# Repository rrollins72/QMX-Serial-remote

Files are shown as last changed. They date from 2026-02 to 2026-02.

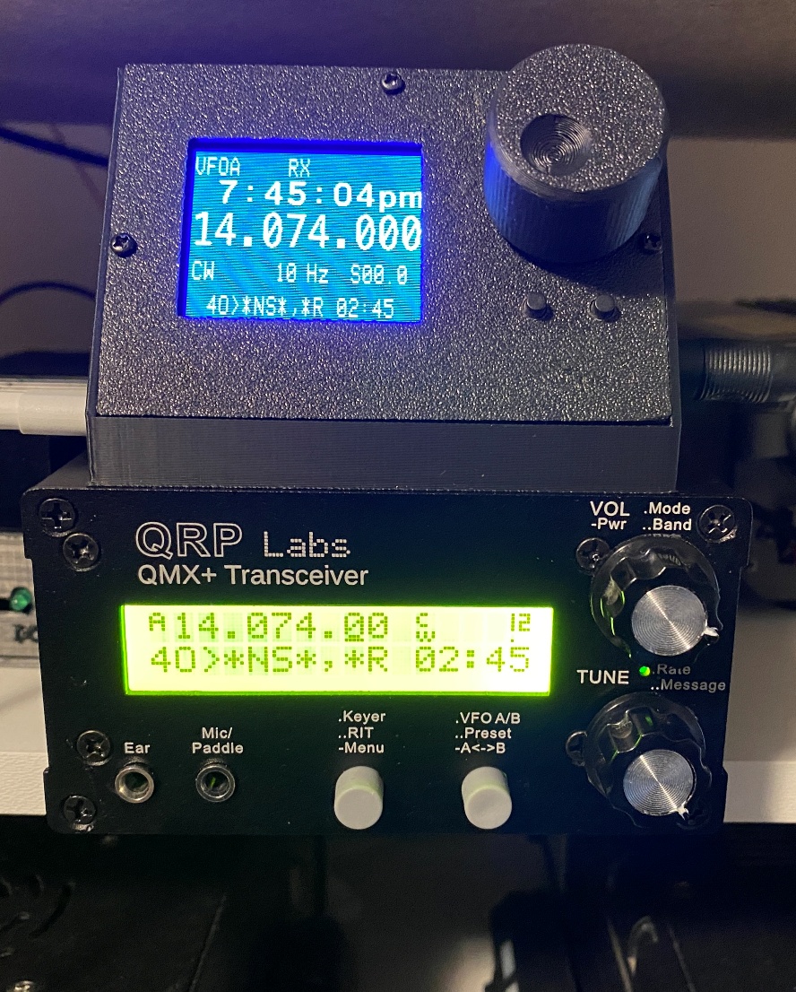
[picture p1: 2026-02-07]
enclosure/operating on qmx+.jpg

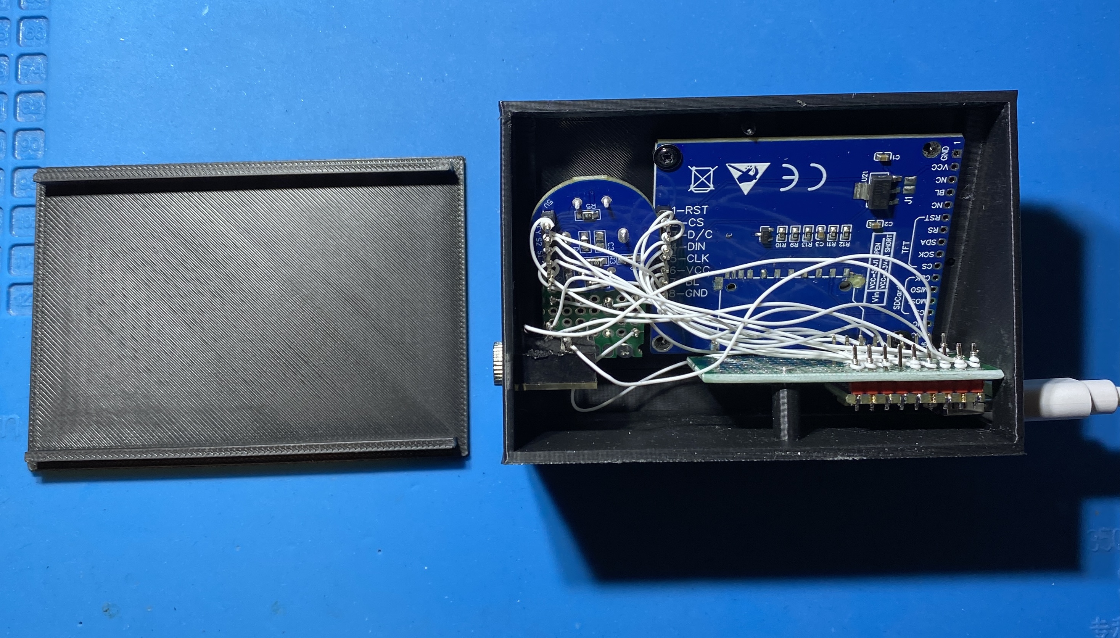
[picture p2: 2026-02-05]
enclosure/internals and wiring.jpg

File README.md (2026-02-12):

# QMX Remote using ESP32

**Fun little project**

A little background…I began experimenting with using a couple inexpensive ESP32
modules when they appeared on Aliexpress for less than \$5. I decided to get an
ESP32-C3 and an ESP32-S3 based small (zero sized) modules. I also had a few
ST7735 based displays that were needing to be utilized, so I decided to build a small
clock that would become an IoT device. That gave me some experience with the
Arduino IDE for ESP32 and graphics on the small display. I thought it would be
fun to figure out if I could talk to my QMX+ using the AUX serial port and the
ESP32 serial port.

Hats off to Hans Summers for a great design on the QMX/QMX+ and his stellar
documentation for the CAT command structures and the tools to monitor the CAT
commands to the unit. That made this effort much easier.

The ESP32-S3 I used is the (equivalent of a) Waveshare ESP32-S3-Zero, (see
https://www.waveshare.com/wiki/ESP32-S3-Zero) and it has a
limited number of IO pins due to the small package size. I decided to use 2
external switches and the rotary encoder switch for function selects, and a 1.8”
120x160 ST7735 display. The basic schematic is as shown:


Note that the display unit I chose had a 3.3V regulator on the board, so it needed 5V to run it. Others that don't have the regulator would run on 3.3V. The 3.3V output from the ESP32-S3-Zero is capable of about 30mA, so it should work OK.

The backlight is always enabled in this scheme. IO3 and IO7 could be used to
turn on and off the backlight, or to add another switch.

I did not put a battery in this set up, so it is powered from the USB-C cable
that is plugged into the ESP32-S3 board. (It draws about 30mA with the display
at full brightness).

I built the first pass on a breadboard and then put it all in a small 3D printed
enclosure with point-to-point wiring. I didn’t attempt to do a PCB for this
project.

Here is a photo of the finished device connected to the QMX+ showing the unit
connected to the QMX+ and operating.



# Operation summary

The remote display will connect to the QMX+ via the AUX serial port.

The serial interface baud rate is set to 19200, with 8N1. This will need to be set up on
the QMX+ using a USB serial port to control the menu system. Go to Main
menu\>Configuration\>System config\>GPS & Ser. Ports: Serial 1 on AUX: ENABLED,
Serial 1 baud: 19200. (Note: I tried using higher baud settings, but that
resulted in a lot of missed data, so settled on 19200).

There are 3 controls on the display:

The rotary knob with button on press, button A (left) and button B (right).

 # Functions

**Rotary knob** will normally adjust the frequency depending on the selected step
size. The step size is changed by a short press on the rotary knob. The step
sizes are 10Hz, 100Hz, 1kHz, 10kHz.

**The band** can also be changed by a double click on the rotary knob (it must be
\~400ms between presses). The band will be shown in the lowest display area. The rotary
knob can be turned to select the band desired, then the knob pressed to verify
and the band will be changed to the selected. (This process needs some
refinement since it required a change to the VFOA frequency to make the change,
so previous VFOA settings are lost).

**The volume** can also be changed by a long press on the rotary knob. The volume
(Audio Gain) is set as desired. This is the raw level and is capable of any value
between 1 and 799. You can set the internal QMX+ volume step, which defaults to
1dB, this is 4 raw steps. I left this at the raw step (.25dB). The Vol is displayed
in the lowest display area, similar to the band selection.

**Button A** is on the left and below the rotary control. It simply controls the
selected VFOA or B.

**Button B** is on the right and below the rotary control. It controls the selected
mode. The modes are cycled through: CW, DIGI, USB, LSB (same as QMX).

Display updates occur on a 1 second increment so there can be some visible lag
on some data presented on the display. The updates from the rotary encoder are
done during the main loop and are near real time.

# Software and IDE build

The Arduino IDE 2.3.7 on Win11 was used to build the code for this project. It will
require the board manager 'esp-32 by Espressif Systems' be installed, the 'OneButton' library and the
'ST7735_LTSM' library to be installed. Because of the limited pins on the
ESP32-S3-Zero package, **a modification to the file noted in the code snippet below needs to be made to
provide an SPI interface on the IO pins used**. This is to change from the
defaults. **Here is the note in the code**:

// NOTE: To map the SPI to available pins, a change to the file in this location is necessary:\
// C:\\Users\\xxxxx\\AppData\\Local\\Arduino15\\packages\\esp32\\hardware\\esp32\\3.x.x\\variants\\waveshare_esp32_s3_zero\\pins_arduino.h\
// Mapping based on the ESP32S3 data sheet - alternate for SPI2\
// static const uint8_t SS = 10; // FSPICS0\
// static const uint8_t MOSI = 11; // FSPID\
// static const uint8_t MISO = 13; // FSPIQ\
// static const uint8_t SCK = 12; // FSPICLK

(in the pins_arduino.h file, change to the pins shown: 10, 11, 13, and 12 and save the file).
This gives the display a fast update capability and works well.

The chosen frequencies for the band-switch are as follows:\
160M 1.9MHz\
80M 3.6MHz\
60M 5.3585MHz\
40M 7.1MHz\
30M 10.125MHz\
20M 14.0475MHz\
17M 18.110MHz\
15M 21.2MHz\
12M 24.930MHz\
10M 28.3MHz\
6M 50.1MHz

These can be changed in the code if needed. As built, they are constants.

I elected to have the display show my local time instead of UTC, though the UTC
is displayed as shown on the QMX+ LCD bottom line. This is easily changed
in the code if desired.

# Enclosure

The STL files for the enclosure are included in the project files. These were
done in Tinker CAD. 

# Caveats and Thoughts

The code for this was built without the use of any extensive buffer management,
and with easily accessible libraries within the Arduino IDE. That said, there is
a slight lag time during the 1 second display refresh on reading the rotary
encoder, so it may feel like it misses once in a while.

Band switching using the double-click on the encoder is not fully consistent,
but it is quite functional. Just takes some getting used to. A third control switch
could be added to make this easier, but I had already built the enclosure by the
time I decided to add band switching.

I also built a version of the code for a larger 2.4" TFT display using the 
ST7789 driver. This is a 320x240 display, so it takes a lot longer to refresh
the screen and it isn't as responsive to the rotary control. It still works well
enough and is bigger to look at. I did not put that version in an enclosure. The code is 
included in this project area.

I did test this with a 15 foot audio cable and didn't see any issues with the 
serial data stream between the remote and the QMX+ (at 19200 baud). It appears
to be quite robust.

The ESP32-S3 has built in WiFi or Bluetooth, so it would be possible to create a server page
that could also show the same information as the display, but that is beyond
what I intended for this effort. It would also draw a lot more power since the
WiFi would need to be active to make it functional. Since ESP32-S3 does not support a Bluetooth SPP
stack it can’t be fully wireless to the QMX+ with simple Bluetooth serial
modules either, so that was not considered.

I don't have a QMX, but the QMX does have the AUX port (internally) so it could be utilized but would require
adding wires and bringing them out to a connector. 

# Improvements?

Adding a small battery to allow the unit to run without power from USB will be
a future update. I will use USB for charging.

# Possible Issues

With the remote running, I have noticed that if I am also running WSJT-X for a while that the QMX+ frequency
for the selected VFO gets set to 0. It is a bit random but quite repeatable. I
have not discovered the cause. A band change either on the remote or in WSJT-X
will set the frequency again. WSJT-X does not show that the frequency has changed,
but the QMX+ and the remote show the frequency of 0. This also happened with JS8Call.
JS8Call did show the frequency change.

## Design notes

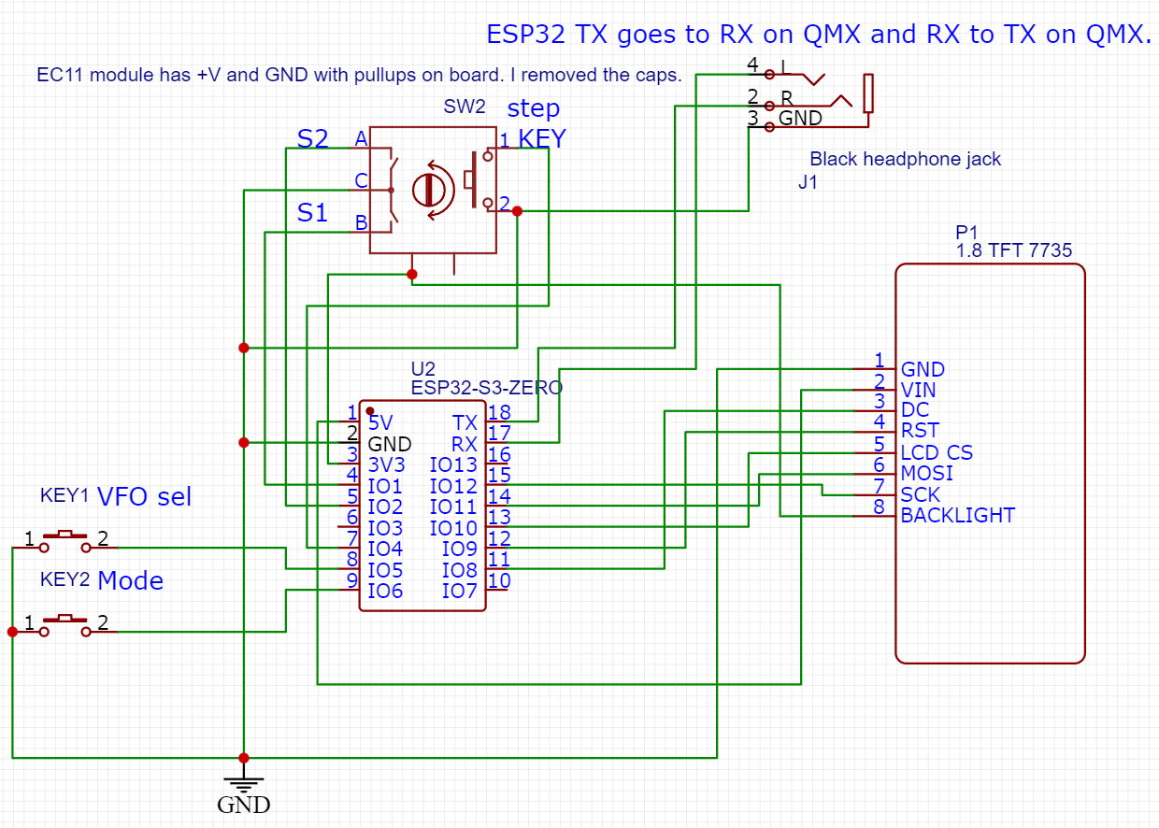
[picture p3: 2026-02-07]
enclosure/schematic.png

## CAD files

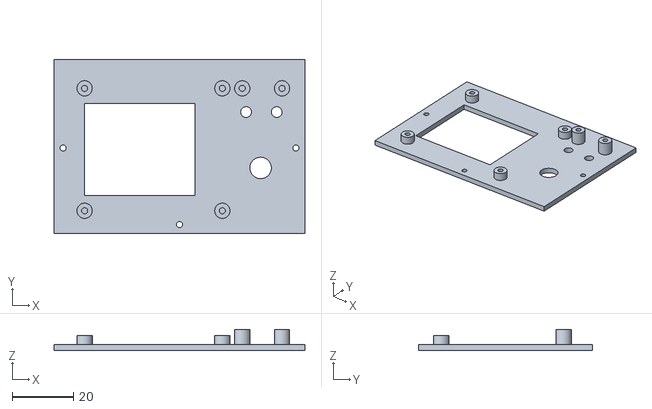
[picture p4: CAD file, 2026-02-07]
enclosure/qmxremote_face.stl
82.0 x 57.0 x 7.00

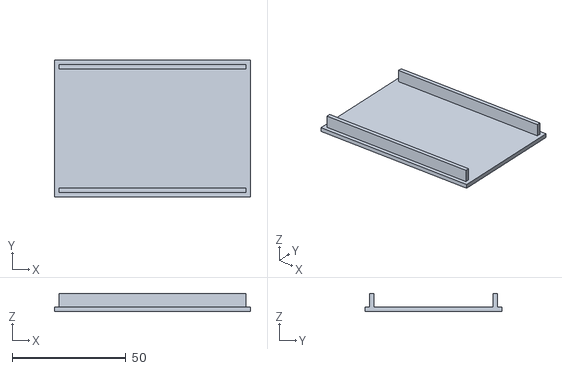
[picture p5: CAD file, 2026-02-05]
enclosure/qmxremote_box-back.stl
86.0 x 60.0 x 8.00

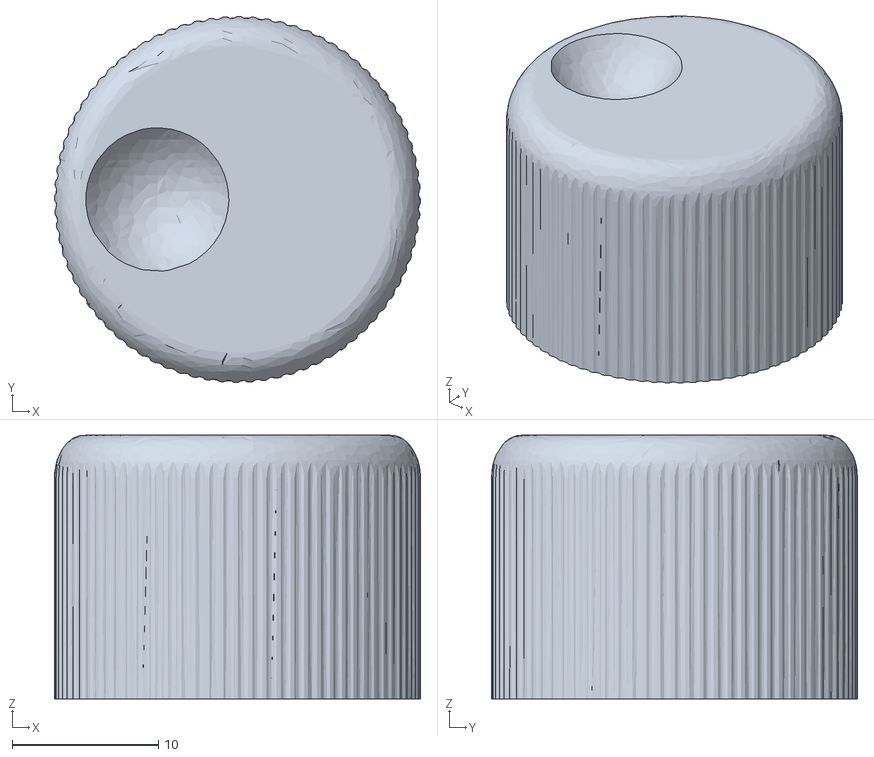
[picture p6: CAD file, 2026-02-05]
enclosure/25mm-knob1.stl
25.0 x 25.0 x 18.0

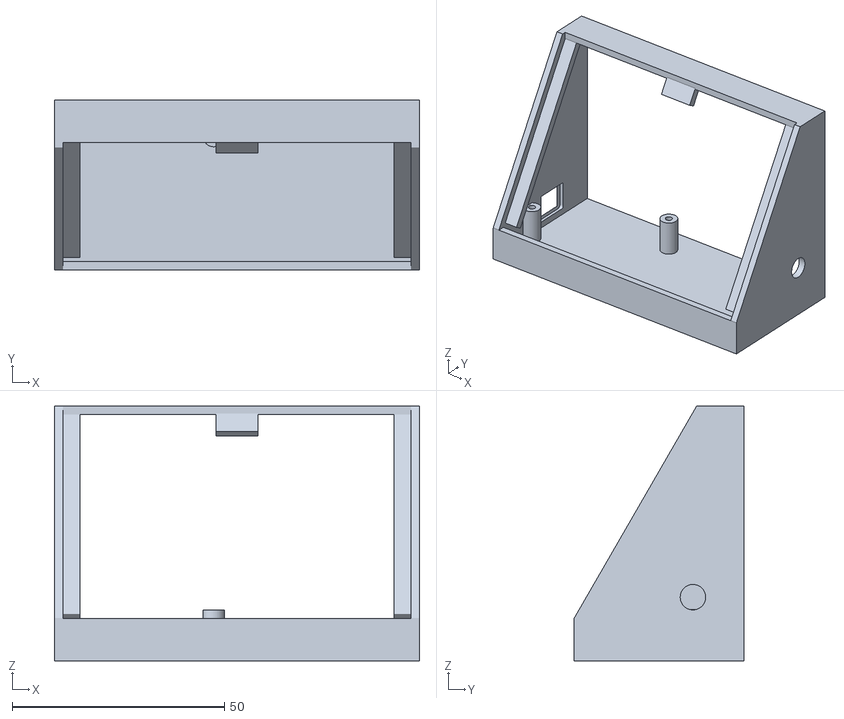
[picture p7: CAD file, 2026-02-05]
enclosure/qmxremote-box.stl
86.0 x 40.0 x 60.0

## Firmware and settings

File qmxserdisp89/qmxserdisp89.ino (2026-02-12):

///////////////////////////////////////////////////////////////////////
//	QMX Remote display
// This sketch using an ESP32-S3 processor and ST7735 display receiving
// serial data on TX/RX UART2 and using a rotary encoder to change frequency
// of the QRP Labs QMX+ tranceiver. It was done as an experiment to see how
// well the ESP32-S3 could handle the load, and it proved that is it quite
// capable.
// A ESP32-S3 Zero platform was used. Readily available for about $5 from Aliexpres
// The display is a 1.8" 160x120 TFT LCD with a ST7735 driver. 
// The Arduino IDE was used for this development. 
//	The esp32 board manager needs to be installed. The Waveshare ESP32-S3-Zero board is selected.
//	The driver for the display is the ST7735_LTSM by Gavin Lyons. Fonts are from that installation.
//		This driver is much faster than the ucg driver, so is necessary for this implementation 
//
//Operation summary
//The remote display will connect to the QMX+ via the AUX serial port. The serial interface baud rate is set to 19200, with 8N1. 
//This will need to be set up on the QMX using a USB serial port to control the menu system.
//Go to Main menu>Configuration>System config>GPS & Ser. Ports: Serial 1 on AUX: ENABLED, Serial 1 baud: 19200.
//(Note: I tried using higher baud settings, but that resulted in a lot of missed data, so settled on 19200).
//
//There are 3 controls on the display:
//The rotary knob with button on press, button A (left) and button B (right).
//Functions:
//Rotary knob will normally adjust the frequency depending on the selected step size. 
//The step size is changed by a short press on the rotary knob. The step sizes are 10Hz, 100Hz, 1kHz, 10kHz. 
//The band can also be changed by a double click on the rotary knob (it must be ~400ms or less). 
//The band will be shown in the lowest display area. 
//The rotary knob can be turned to select the band desired, then the knob pressed to verify 
//and the band will be changed to the selected. 
//(This process needs some refinement since it required a change to the VFOA frequency to make the change, 
//so previous VFOA settings are lost).
//The rotary knob can also be used to adjust the volume with a long press (>600ms).
//The volume (Analog Gain) is shown in the lower LCD and can be adjusted to a desired listening level,
//then a short press on the knob will set it to that and return to frequency adjust.
//Button A is on the left and below the rotary control. It simply controls the selected VFOA or B. 
//Button B is on the right and below the rotary control. It controls the selected mode. 
//The modes are cycled through: CW, DIGI, USB, LSB (same as QMX).
//
//Display updates occur on a 1 second increment so there can be some visible lag on some data presented on the display. 
//The updates from the rotary encoder are done during the main loop and are near real time. 
//The current build is set up for displaying MST from the clock, but this can be turned off or adjusted
//
//  
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
//////////////////////////////////////////////////////////////////////////
//
// The signals on the ST7735 and hook up to the ESP32-S3 Zero are as follows:
// ST7735   S3
//  GND     GND (pin 2)
//  VDD     5V(pin 1) The display has a 3.3V regulator on it-needs 5v.
//  SCL     SCK (GP12)
//  SDA     MOSI (GP11)
//  RST     GP9 
//  DC(RS)  GP8      
//  CS(SS)  GP10 
//  BKLT    to 3.3V on pin 1
//
/////////************** NOTE *******************************************
//  NOTE: To map the SPI to available pins, a change to the file in this location is necessary: 
//  C:\Users\xxxxx\AppData\Local\Arduino15\packages\esp32\hardware\esp32\3.x.x\variants\waveshare_esp32_s3_zero\pins_arduino.h:
//   Mapping based on the ESP32S3 data sheet - alternate for SPI2
//    static const uint8_t SS = 10;    // FSPICS0
//    static const uint8_t MOSI = 11;  // FSPID
//    static const uint8_t MISO = 13;  // FSPIQ
//    static const uint8_t SCK = 12;   // FSPICLK
//
// IF THERE IS AN UPDATE TO THE ESP32 PACKAGE THEN THIS WILL CHANGE, so need to be aware of it
//
/////////////////////////////////////////////////////////////////////////
//
/////////****************************************************************
// The serial interface will be based on the OnReceive demo structure-it is clean works well
// See QMX CAT document for information
////////////////////////////////////////
//

// libraries for display
#include "ST7789_LTSM.hpp"
// Included Fonts 
#include <fonts_LTSM/FontArialRound_LTSM.hpp>
#include <fonts_LTSM/FontRetro_LTSM.hpp>
#include <fonts_LTSM/FontGroTesk_LTSM.hpp>
#include <fonts_LTSM/FontGroTeskBig_LTSM.hpp>
#include <fonts_LTSM/FontSevenSeg_LTSM.hpp>
#include <fonts_LTSM/FontMint_LTSM.hpp>

////Display initialize
ST7789_LTSM myTFT;
bool bhardwareSPI = true; // true for hardware spi, false for software

/////// EC-11 rotary and buttons use ezButton
#include <ezButton.h>  // the library to use for SW button and other buttons
#include <Arduino.h>  // included for general serial use

/////// Onebutton ////////////
#include <OneButton.h>

///// Defines for IO pins used
#define CLK_PIN 1  // ESP32 pin gp1
#define DT_PIN 2   // ESP32 pin gp2
#define SW_PIN 4   // ESP32 pin gp4
#define BUTTON1 5  // GP5   general purpose button inputs
#define BUTTON2 6  // GP6

#define DIRECTION_CW 0   // clockwise direction
#define DIRECTION_CCW 1  // counter-clockwise direction

#define BAUD      19200 // Should be a reasonable speed for comms?
#define RXPIN     44     // GPIO 44 => RX for Serial2
#define TXPIN     43     // GPIO 43 => TX for Serial2

//////////////////// general declarations for global use and constants ///////////////////
// Rotary control globals
volatile int counter = 0;
volatile int direction = DIRECTION_CW;
volatile unsigned long last_time;  // for debouncing
volatile int statecnt = 0;

// Thresholds for rotary button press detects(milliseconds)
const int ShortPressTop  = 250;
const int LongPressBase   = 800;
const int DoubleClickGap = 400;
// Variables to track timing
unsigned long pressedTime  = 0;
unsigned long releasedTime = 0;
bool isWaitingForDouble    = false;
bool longPressDetected     = false;
bool VolProc = false;
int bstate = 0;		//button state is 0 to idle, 1 for long, 2 for double

int prev_counter = 0;
// The ezButton library is helpful for button management
//ezButton button(SW_PIN);	// create ezButton objects that attach to pins;
ezButton button1(BUTTON1);	//button for vfo selection
ezButton button2(BUTTON2);	//button for mode selection

OneButton button(SW_PIN, true); //active low true

// for S3 zero with RGB LED the IO is 21
#define RGB_BUILTIN 21
#define DEBUG 0

// Timer controls
unsigned long prevmils = 0;
unsigned long prevmils1 = 0;

/*************************************/
volatile size_t received_bytes = 0;
unsigned int fifoFull = 38;   // max data to receive
char Rcvbuf1[40];	// buffer to receive data
bool Rcvbufavail = 0;
bool Serconnavail = 0;	//set when a serial connection is valid
char FreqA[12] = "00014047500";
char FreqB[12] = "00007050000";
char Frcv[2] = "0";
char Ftrx[2] = "0";
char freqbuf[15];
char freqbuf1[15];
char AudGn[6] = "0180";
char timedat[9] = "12:00:00";     //time data hh:mm:ss
char timedat1[3];     // for am or pm
char timehr[3];       //HR portion
int AudGnVol = 180;	//base audio volume
int timehrdat;
int timelocalhr;
int rxtxchk = 0;   //receive/transmit state rx=0, tx=1
// For displaying local time offset from UTC from TM command
const int timelocal = -7;     //GMT offset for local MST
const bool TwelveHour = 1;	// For displaying 12 or 24 hour format
char smeterdat[6] = "00.1";   //smeter data in db xx.x 
char swrdat[6] = "1.00";      //swr reading x.xx:1
char lcddat[20] = {};     //lcd data-second line starts at 15 (16 bytes in)
//char infodat[36] = {};	  //info response 
char modedat[4] = {};     //mode info 1=LSB, 2=USB, 3=CW, 6=DIGI (FSK), 7=CWR
unsigned int modex = 2;	  // mode number as above
unsigned int frecvfo = 0; //receive vfo =0 for A, 1 for B, 3 for split
unsigned int ftrxvfo = 0; //same as receive vfo
unsigned int vfoaorb = 0;	//0=VFOA 1=VFOB
long Vfreqa = 0;
long Vfreqb = 0;
long stepset = 10;	//Step size in Hz for rotary step

int bandsel = 5;	//11 bands. 0=160m..10=6m 5=20m
bool bandselproc = 0;	//if in band select process

// Display constants
const char modLSB[] = "LSB  ";
const char modUSB[] = "USB  ";
const char modCW[] = "CW   ";
const char modCWR[] = "CWR  ";
const char modDIG[] = "DIGI ";
const char modDIGR[] = "DIGIR";
const char vfoAstr[] = "VFOA";
const char vfoBstr[] = "VFOB";
const char vfoSplit[] = "SPLIT";
const char stepHZ[] = "Hz  ";
const char stepkHZ[]= "kHz";
const char txstr[] = "TX";
const char rxstr[] = "RX";

// band set strings
const char bandtxt[11][10] = {"160m band"," 80m band"," 60m band"," 40m band"," 30m band"," 20m band"," 17m band"," 15m band"," 12m band"," 10m band","  6m band"};
//const char band160set[] = "00001900000";	//160M	1.9MHz
//const char band80set[] = "00003600000";		//80M	3.6MHz
//const char band60set[] = "00005358500";		//60M	5.3585MHz
//const char band40set[] = "00007100000";		//40M	7.1MHz
//const char band30set[] = "00010125000";		//30M	10.125MHz
//const char band20set[] = "00014150000";		//20M	14.150MHz
//const char band17set[] = "00018110000";		//17M	18.110MHz
//const char band15set[] = "00021200000";		//15M	21.2MHz
//const char band12set[] = "00024930000";		//12M	24.930MHz
//const char band10set[] = "00028300000";		//10M	28.3MHz
//const char band6set[] = "00050100000";		//6M	50.1MHz
const char bandsets[11][12] = {"00001900000","00003600000","00005358500","00007100000","00010125000","00014047500","00018110000","00021200000","00024930000","00028300000","00050100000" };

// Command constants
const char LCcmd[] = "LC;";   //LCD command-receive 35 chars
const char FAcmd[] = "FA;";   //Freq VFOA command-receive 14 chars, send 14 chars
const char FBcmd[] = "FB;";   //Freq VFOB command-receive 14 chars, send 14 chars
const char FRcmd[] = "FR;";   //Receive VFO command-receive 3 chars, send 3 chars
const char FTcmd[] = "FT;";   //Transmit VFO command-receive 3 chars, send 3 chars
const char MDcmd[] = "MD;";   //Mode command-receive 4 chars or send 4 chars
const char SMcmd[] = "SM;";   //Smeter command-receive 6 chars
const char TMcmd[] = "TM;";   //Time command-receive 9 chars
const char TQcmd[] = "TQ;";   //Tx/Rx command-receive 3 chars
const char SWcmd[] = "SW;";   //SWR during transmit-receive 6 chars
const char AGcmd[] = "AG;";   //Audio Gain command-receive 6 chars

///////////////////////////////////////////////////////////////
// This is called from the main loop to detect rotation changes
// There is sufficient main loop timing to make this work
///////////////////////////////////////////////////////////////
void rotloop () {
    if (statecnt == 0){
      if ((digitalRead(CLK_PIN) == LOW)&&(digitalRead(DT_PIN) == LOW)){
        statecnt = 1;
      }
    }
    if (statecnt == 1){
      if (digitalRead(CLK_PIN) == HIGH){
        statecnt = 2;
        last_time = millis();
      }
    }
    if (statecnt == 2){
      if ((millis() - last_time) > 2){
          if ((digitalRead(CLK_PIN) == HIGH)&&(digitalRead(DT_PIN) == HIGH)){
          // the encoder is rotating in counter-clockwise direction => decrease the counter
          counter--;
          direction = DIRECTION_CCW;
          statecnt = 0;
          }
          if ((digitalRead(CLK_PIN) == HIGH)&&(digitalRead(DT_PIN) == LOW)) {
          // the encoder is rotating in counter-clockwise direction => decrease the counter
          counter++;
          direction = DIRECTION_CW;
          statecnt = 0;
          }         
      }
    }
}

void RotButtonCheck(){
	button.tick(); // Monitor button state
  if (bstate == 1){	//long press
	  VolProc = true;
	    Serial2.write(AGcmd);	//request current audio gain on long press
		delay(5);  
  }
  else if (bstate == 2){ //double press
	    bandselproc = 1;  //enter band select
  }
}

// SHORT PRESS: Acts as the stop or regular press
void handleClick() {
  if (bstate != 0) {
    bstate = 0;
	if (bandselproc) {
		BandChgSnd();	//if in bandsel state, clear it and send command
		bandselproc = 0;
	}
	VolProc = 0;
  } 
  else {
    Serial.println("Short Press: Standard Action.");
	  if (stepset == 10) stepset = 100;
    else if (stepset == 100) stepset = 1000;
    else if (stepset == 1000) stepset = 10000;
    else if (stepset == 10000) stepset = 10;
    Botline();  // update display
  }
}
// DOUBLE PRESS: Starts the double routine
void handleDoubleClick() {
  if (bstate == 0) {
    bstate = 2;
  }
}

// LONG PRESS: Starts the long routine
void handleLongPressStart() {
  if (bstate == 0) {
    bstate = 1;
  }
}

////////////// Top line of the display ///////////////////
///////// Print time if receiving data from QMX, otherwise just show no connection /////
void Topline (){
  if (Serconnavail) {
    myTFT.setFont(FontGroTesk);
    myTFT.setTextColor(myTFT.C_WHITE, myTFT.C_BLUE);
    myTFT.setCursor(0,5);
    if (vfoaorb == 0) myTFT.print(vfoAstr);	//which vfo to show
    if (vfoaorb == 1) myTFT.print(vfoBstr);
    myTFT.setCursor(120,5);
    if (rxtxchk == 0) {
      myTFT.print(rxstr);
      myTFT.setCursor(160,5);
      myTFT.print("         ");
    }    
    else if (rxtxchk == 1) {
      myTFT.print(txstr);
      myTFT.setCursor(160,5);
      myTFT.print(" SWR ");
      myTFT.print(swrdat);
    } 						
    myTFT.setFont(FontMint);
    if (!TwelveHour) {
      myTFT.setCursor(35,35);
      myTFT.print (timedat);
    }
    else {
  // This converts the hour to local time for display
        timehrdat = atoi(timehr);     //to convert to local time for display
        timelocalhr = timehrdat+timelocal;  // Local offset from UTC
        if (timelocalhr < 0) timelocalhr = timelocalhr+24;
        if (TwelveHour) {
          if (timelocalhr >= 12) {
            if (timelocalhr > 12) timelocalhr = timelocalhr-12;
          timedat1[0] = 'p';
          }
          else {
            if (timelocalhr == 0) timelocalhr = 12;	
            timedat1[0] = 'a';
          }
          timedat1[1] = 'm';
          timedat1[2] = 0;
        }
        itoa (timelocalhr,timehr,10);
        if (timelocalhr < 10) {   // can pad with a 0 or space if leading 0 not desired
          if (TwelveHour) timedat[0] = ' ';
          else timedat[0] = '0';
          timedat[1] = timehr[0];
        }
        else {
          timedat[0] = timehr[0];
          timedat[1] = timehr[1];
        }
      myTFT.setCursor(50,40);
      myTFT.print (timedat);
      myTFT.print ("  ");
      myTFT.setFont(FontGroTesk);
      myTFT.setCursor(250,40);
      myTFT.print (timedat1);
    }
  }
  else {
    myTFT.setFont(FontGroTesk);
    myTFT.setCursor(50,40);
    myTFT.print ("*******        ");
    myTFT.setCursor(50,40);
    myTFT.print ("no coms ");
  }
}

//////////// lower display area, for mode and step and Smeter //////////
void Botline (){
	myTFT.setFont(FontGroTesk);
	myTFT.setCursor(2,165);
  switch (modex){
      case 1:
          myTFT.print (modLSB);
          break;
      case 2:
          myTFT.print (modUSB);
          break;
      case 3:
          myTFT.print (modCW);
          break;
      case 6:
          myTFT.print (modDIG);
          break;
      case 7:
          myTFT.print (modCWR);
          break;
      case 9:
          myTFT.print (modDIGR);
          break;
  }
  myTFT.setCursor(100,165);
  switch (stepset){
    case 1:
      myTFT.print("  ");    
      myTFT.print(stepset);
      break;
    case 10:
      myTFT.print(" ");   
      myTFT.print(stepset);
      break;
    case 100:
      myTFT.print(stepset);
      break;  
    case 1000:
      myTFT.print("  ");      
      myTFT.print(stepset/1000);
      break;
    case 10000:
      myTFT.print(" ");
      myTFT.print(stepset/1000);
      break;
    case 100000:
      myTFT.print(stepset/1000);
      break;
  }
  myTFT.setCursor(160,165);
  if (stepset < 1000) myTFT.print(stepHZ);
  else myTFT.print (stepkHZ);
  myTFT.setCursor(230,165);
  myTFT.print ("S");
  myTFT.print (smeterdat);
}

/////////////// Bottom line where QMX LCD info is displayed //////
void LCbotline() {
	myTFT.setFont(FontGroTesk);
	myTFT.setCursor(5,200);
	if (bandselproc){
		myTFT.print(bandtxt[bandsel]);
		myTFT.print("     ");
			} 
  else if (VolProc) {
    myTFT.print("Vol ");
    myTFT.print(AudGnVol);
		myTFT.print("     ");    
  }
  else  {
    myTFT.setCursor(5,200);
    myTFT.print(lcddat);
  }
}

/////////// When a frequency change occurs, send from here ///////
void FreqChgsend(){
  if (vfoaorb == 0) {  //VFOA
      sprintf(freqbuf,"%ld", Vfreqa);
      Serial2.write("FA");
      Serial2.write(freqbuf);
      Serial2.write(";");
      Serial2.write(FBcmd);
      delay(10);						   
  }
  if (vfoaorb == 1) { //VFOB
      sprintf(freqbuf,"%ld", Vfreqb);
      Serial2.write("FB");
      Serial2.write(freqbuf);
      Serial2.write(";");
      Serial2.write(FAcmd);
      delay(10);
  }
  Serial2.write("FR");
    if (!vfoaorb) Serial2.write("0");
    else Serial2.write("1");
    Serial2.write(";");
}

/////////// Frequency display update  ///////////
void Frequpdate(){
  long lvalue = 1;
  if (vfoaorb == 0) lvalue = Vfreqa;  //VFOA
  else if (vfoaorb == 1) lvalue = Vfreqb;  //VFOB
  sprintf(freqbuf1, "%ld", lvalue);
  if (lvalue >= 10000000){
  strncpy(freqbuf, freqbuf1, 2);
  freqbuf[2] = '.'; // Insert the character
  strcpy(freqbuf + 3, freqbuf1 + 2); // Copy elements after the insertion point
  strncpy(freqbuf1, freqbuf, 6);
  freqbuf1[6] = '.';
  strcpy( freqbuf1+7,freqbuf+6);
  }
  else if (lvalue < 10000000){
  strncpy(freqbuf, freqbuf1, 1);
  freqbuf[1] = '.'; // Insert the character
  strcpy(freqbuf + 2, freqbuf1 + 1); // Copy elements after the insertion point
  strncpy(freqbuf1, freqbuf, 6);
  freqbuf1[5] = '.';
  strcpy( freqbuf1+6,freqbuf+5);    
  }
	myTFT.setFont(FontGroTeskBig);
	myTFT.setTextColor(myTFT.C_WHITE, myTFT.C_BLUE);
  myTFT.setCursor(0,85);
  if (lvalue < 10000000) myTFT.print("0");
  myTFT.print(freqbuf1);	//which vfo to show
}

///////////////////////////////////////////////////////////////////////
// This is a UART callback function that will be activated on UART RX events
///////////////////////////////////////////////////////////////////////
void onReceiveFunction(void) {
  size_t available = Serial2.available();
  received_bytes = received_bytes + available;
//  Serial.printf("%d bytes rcvd: ", available);
  int i=0;
  while (available--) {
	Rcvbuf1[i] = (char)Serial2.read();
//    Serial.print(Rcvbuf1[i]);
    i++;
  }
  Rcvbufavail = 1;
//  Serial.println();
  ParseRcv();
}
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
void loop() {
  unsigned long currentMillis = millis();	
  rotloop();
  if (prev_counter != counter) {
    if (direction == DIRECTION_CW){
      if (bandselproc){
        bandsel++;
        if (bandsel > 10) bandsel = 0;
		LCbotline();
      }
	    else if (VolProc){
		    AudGnVol++;
		    if (AudGnVol > 799) AudGnVol = 799;
        VolChgSnd();
        LCbotline();
	    }
      else if (vfoaorb == 0) {
        Vfreqa = Vfreqa+stepset;
		    FreqChgsend();
        Frequpdate();
	    }
      else if (vfoaorb == 1) {
        Vfreqb = Vfreqb+stepset;
		    FreqChgsend();
        Frequpdate();
	    }
    }
    if (direction == DIRECTION_CCW){
      if (bandselproc){
        bandsel--;
        if (bandsel < 0) bandsel = 10;
        LCbotline();
      }
      else if (VolProc){
        AudGnVol--;
        if (AudGnVol < 1) AudGnVol = 1;
        VolChgSnd();
        LCbotline();
      }
      else if (vfoaorb == 0) {
        Vfreqa = Vfreqa-stepset;
		    FreqChgsend();		
        Frequpdate();
	    }
      else if (vfoaorb == 1) {
        Vfreqb = Vfreqb-stepset;
		    FreqChgsend();
        Frequpdate();
	    }       
	  }
    prev_counter = counter;
  }
  
 // Check for rotary button
 RotButtonCheck();	// Process the rotary button pushes

// Check for button 1
  button1.loop();     // This button changes the VFO from current to next
  if (button1.isPressed()) {
    if (vfoaorb == 0) vfoaorb = 1;
    else if (vfoaorb == 1) vfoaorb = 0;
    Serial2.write("FR");
    if (!vfoaorb) Serial2.write("0");
    else Serial2.write("1");
    Serial2.write(";");
  }

// Check for button2
  button2.loop();     // This button changes the mode of the xceiver: Rotates thru CW,DIGI,USB,LSB
  if (button2.isPressed()) {
    if (modex == 2) modex = 1;
    else if (modex == 1) modex = 3;
    else if (modex == 3) modex = 6;
    else if (modex == 6) modex = 2;
    else if (modex > 6) modex = 2;
    Serial2.write("MD");
    Serial2.write(modex + '0'); // create ascii number for mode and send
    Serial2.write(";");
  }

// one second updates-general status and time
// Delays are for processing the serial data requested
// The values used let each command to process properly based on received bytes
	if (currentMillis - prevmils1 > 1000)  { //update clock each second
    Chkserconn();   //used the TM command to look for serial connection
		Topline();
    if (Serconnavail){
      Serial2.write(FAcmd);   //get VFOA 
      delay(10);
      Serial2.write(FBcmd);   //get VFOB 
      delay(10);
      Frequpdate(); // Display freq for selected VFO
      Serial2.write(MDcmd);   //mode command request
      delay(4);
      Serial2.write(TQcmd);   //get rx/tx mode 
      delay(4);
      if (rxtxchk == 1){
        Serial2.write(SWcmd);
        delay(4);
      }
      Serial2.write(SMcmd);   //Smeter request
      delay(8);
      Serial2.write(FRcmd);   //get selection
      delay(4);
      Botline();
      Serial2.write(LCcmd);   //get LC data for bottom row
      delay(18);
      LCbotline();
    }
		prevmils1 = currentMillis;
	}
} //Main loop end
